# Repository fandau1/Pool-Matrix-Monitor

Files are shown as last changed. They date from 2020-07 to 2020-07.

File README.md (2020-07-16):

# Pool-Matrix-Monitor




**Simple arduino pool clock with sensors**

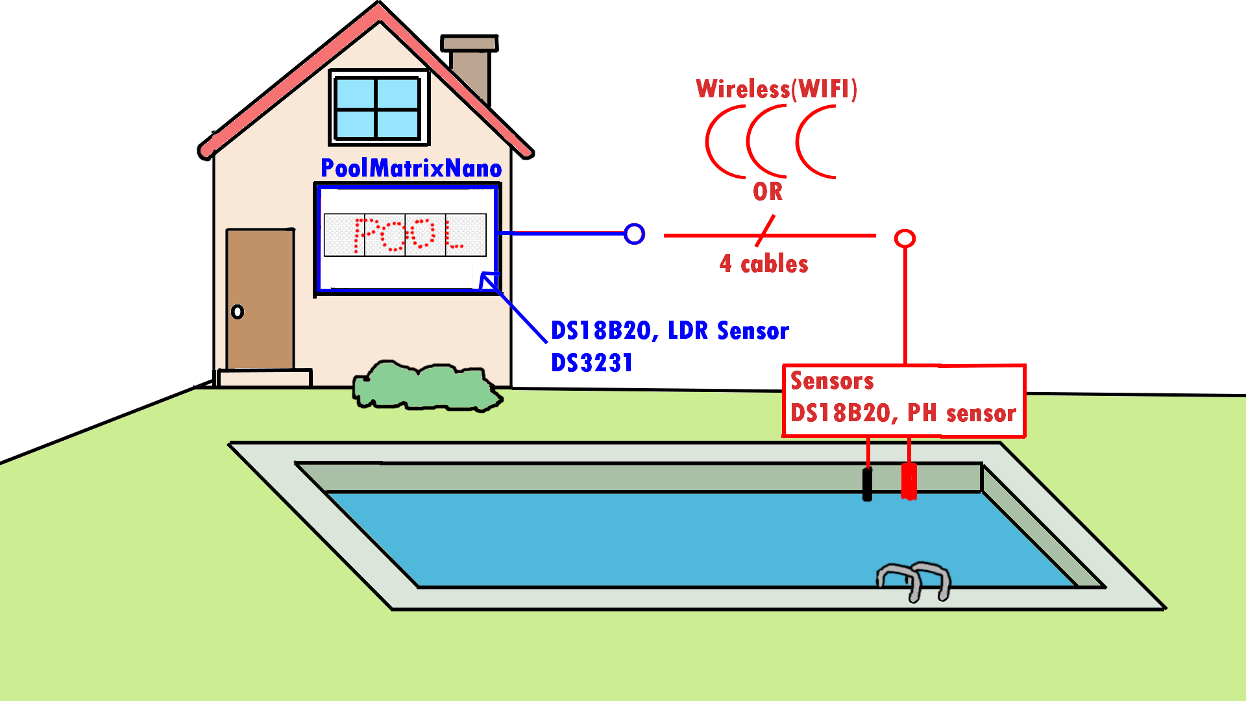
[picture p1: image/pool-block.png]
  

Pool-Matrix-Monitor is pool clock with temperature, ph sensor and all this data send to ThingSpeak, or GET to server.

# Main Features
  * [x] Matrix display in cycle(TIME,"Outsite",OUTSITE_TEMPERATURE,"Pool",POOL_TEMPERATURE,"PH sensor", POOL_PH)
  * [x] Measurement of Sensors light, temperature, ph
  * [x] Auto detection connected sensors
  * [x] Auto correct summer and standart time (DST correct)

# How to use?
  **1.** Choose Optimal Board version. Project is saved in **__NAME_OF_BOARD__/...** (example **PoolMatrixNano/...**)  
  **2.** Create circuit or pcb  
  **3.** Upload Arduino Software with Arduino IDE  
  **4.** Put sensors in conectors and you can put in box  

  **[Full Tutorial in CZ language here](https://github.com/fandau1/Pool-Matrix-Monitor/blob/master/TutorialCZ.md)**

# Boards Versions
I have prepering more version of this project so you can choose which is best for you.

|  Boards Versions  | MCU | transfer type pool sensor | SW release | HW release |  Price  |
| :---: |:---:| :---: | :---: | :---: | :---: |
| [PoolMatrixNano](#poolmatrixnano) | Arduino nano | cable | PMN-v1.0 | PMN-v1.1H | ~13$ |
| PoolMatrixNanoEth | Arduino nano | cable | Not realesed | Not realesed |  |
| PoolMatrixESP32 | ESP32 | cable OR WIFI | Not realesed | Not realesed |  |
| PoolMatrixESP8266 | ESP8266 | cable OR WIFI | Not realesed | Not realesed | |

**for more info with tutorial go to section [All Boards list](boards.md)**

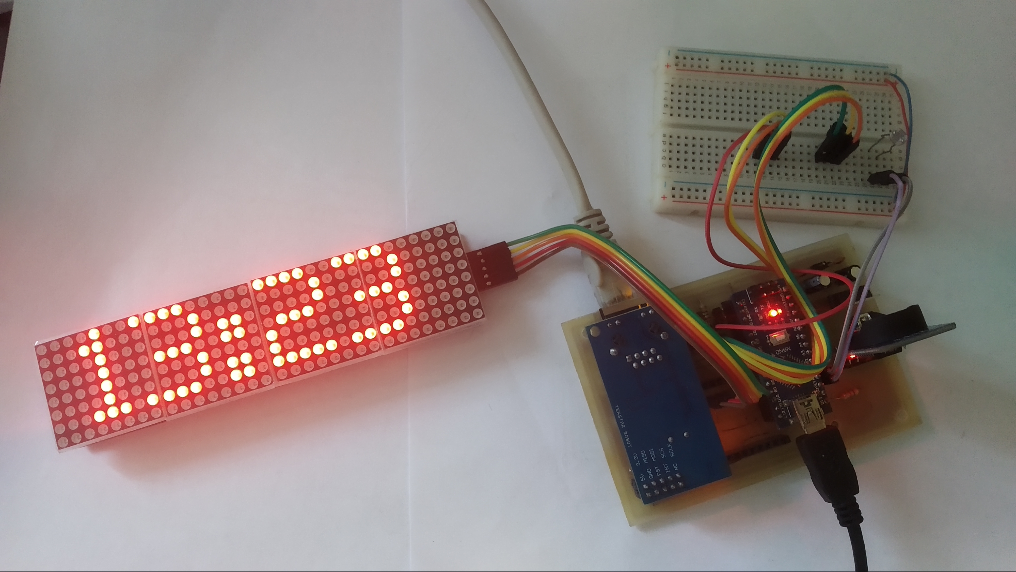
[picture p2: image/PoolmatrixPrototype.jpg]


## PoolMatrixNano [[Full version](boards.md#poolmatrixnano)]
**Offline board arduino nano mcu with rtc, matrix display and sensors. Simple cheap and easy for home pool.**

**Basic**
  * Arduino nano
  * DS3231
  * MAX7219 Matrix LED Display Module 4-v-1
  * some resistors

**Optional**
  * DS18B20 *- temperature sensor*
  * Photo Resistor
  * PH sensor PH-4502C

# PCB
  I designed PCB oneside only with some proclaim wires :). So, you can easily create in home or you can solder on prototype pcb. PCB is saved in **__NAME_OF_BOARD__/pcb/** you can choose more version(no ethernet, etc.).

  **PS: In this time you can choose only PoolMatrixNano**

# Installation
 * Download below library and upload code with Arduino IDE to arduino nano. Code is saved in **__NAME_OF_BOARD__/src/** you can choose more version(no ethernet, etc.).

 **In MD_Parola library you must to disable all advance function for a smaller size.**

 **PS: In this time you can choose only PoolMatrixNano**

**Library**
  * [MD_MAX72xx](https://github.com/MajicDesigns/MD_MAX72XX) - *from MajicDesigns*
  * [RTClib](https://github.com/adafruit/RTClib) - *from adafruit*
  * [DallasTemperature](https://github.com/milesburton/Arduino-Temperature-Control-Library) - *from milesburton*
  * [Ethernet2](https://github.com/adafruit/Ethernet2) - *from adafruit*
  * [DST_RTC](https://github.com/andydoro/DST_RTC) - *from andydoro*  

## Planned Features
  * [ ] send data to database (MYSQL), ThingSpeak
  * [ ] ESP8266/ESP32 version
  * [x] NTP synchronize time

## Support
Project is supported if you have any problem contact me. Please give me a :star: if you like my project. If you have any problem feel free and contact me.

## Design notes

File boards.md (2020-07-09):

# Boards Versions
|  Board Versions  | MCU | transfer type pool sensor | SW release | HW release |  Approximate price  |
| :---: |:---:| :---: | :---: | :---: | :---: |
|[PoolMatrixNano](#poolmatrixnano)  | Arduino nano | cable | PMN-v1.1H | PMN-v1.0 | ~13$ |
| PoolMatrixNanoEth | Arduino nano | cable | Not realesed | Not realesed |  |
| PoolMatrixESP32 | ESP32 | cable OR WIFI | Not realesed | Not realesed |  |
| PoolMatrixESP8266 | ESP8266 | cable OR WIFI | Not realesed | Not realesed | |

# PoolMatrixNano
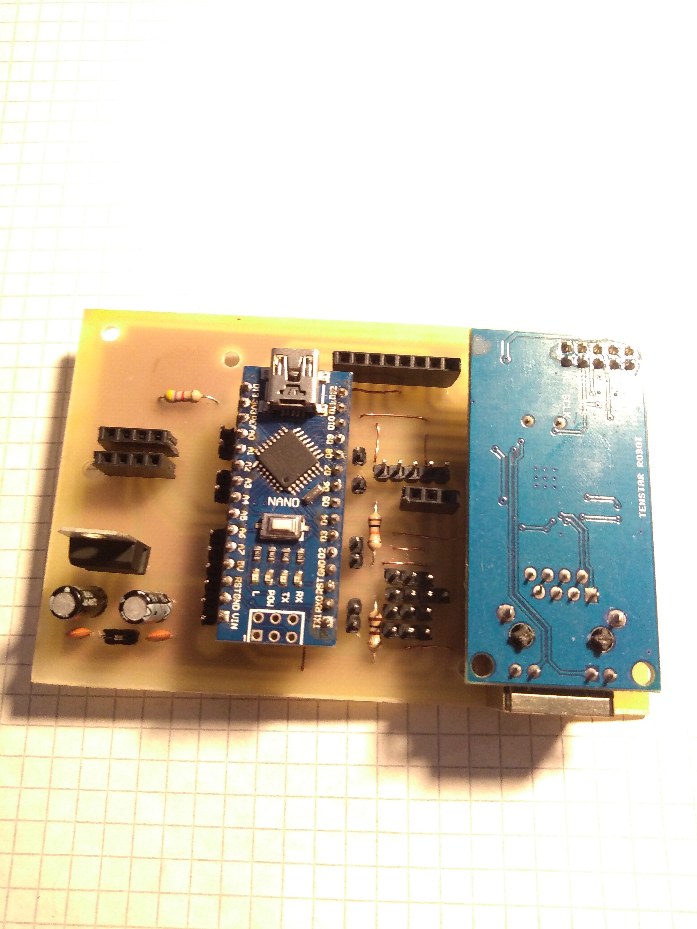
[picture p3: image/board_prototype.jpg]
 

Offline arduino nano mcu with rtc, matrix display and sensors. Simple cheap and easy for home pool.

## Components
**Basic**
  * Arduino nano
  * DS3231
  * MAX7219 Matrix LED Display Module 4-v-1
  * some resistors
  
**Optional**
  * DS18B20 *- temperature sensor*
  * Photo Resistor
  * PH sensor PH-4502C 
    
## Schematic
|  Arduino  | |  Modules  |
| :---: |---|  :---: |
| D13(SCK) | -> |  MATRIX(CLK) |
| D11(MOSI) | -> |  MATRIX(DIN) |
| D10(SS) | -> | MATRIX(CS) |
| D5(PWM) | -> | DS18B20 |
| A5(SCL) | -> | DS3231(SCL) |
| A4(SDA) | -> | DS3231(SDA) |
| A1 | -> | PH sensor |
| A0 | -> | Photo resistor(LUX meter) |

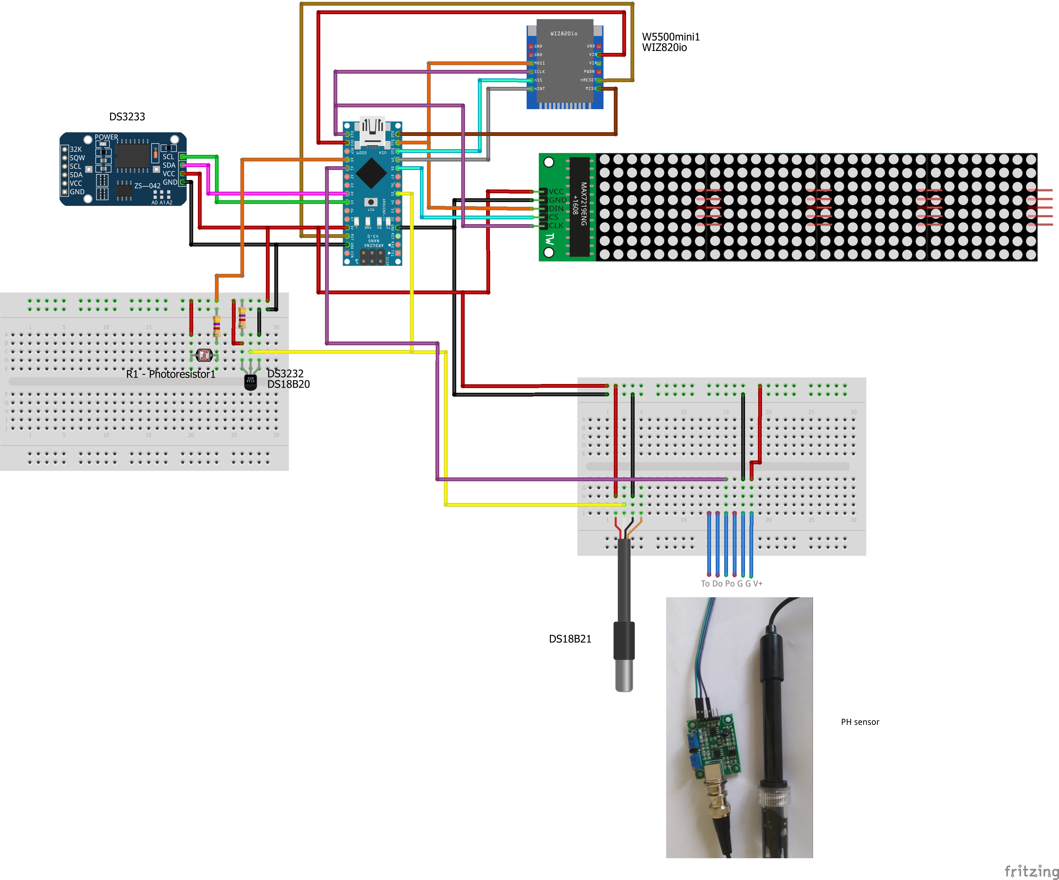
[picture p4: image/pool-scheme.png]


## PCB
I designed PCB oneside only with some proclaim wires :). So, you can easily create in home or you can solder on prototype pcb. PCB is saved in **pcb/...** you can choose more version(no ethernet, etc.).

## Tutorial
First, it is important to engage the schematic. You can plug it into a breadboard or use my pcb design. It is also possible to connect a circuit to a prototype pcb if you do not have the ability to produce a pcb. PCB is saved in **pcb/...** you can choose more version(no ethernet, etc.).

If you do not want any sum in the optional section, you do not need to use it. The code will work. So if you don't want a ph sensor, you don't have to connect it. 

**So far, I do not recommend using a ph sensor too much, because it seems inaccurate and expensive.**

After you complete HW section. You can upload code with Arduino IDE(must download all library). Code is saved in **src/...** you can choose more version(no ethernet, etc.).

**In *MD_Parola* library you must to disable all advance function for a smaller size.**

And your pool-matrix-monitor is done. You can test it and choose in some nice box.

if you have any problems feel free to contact me.

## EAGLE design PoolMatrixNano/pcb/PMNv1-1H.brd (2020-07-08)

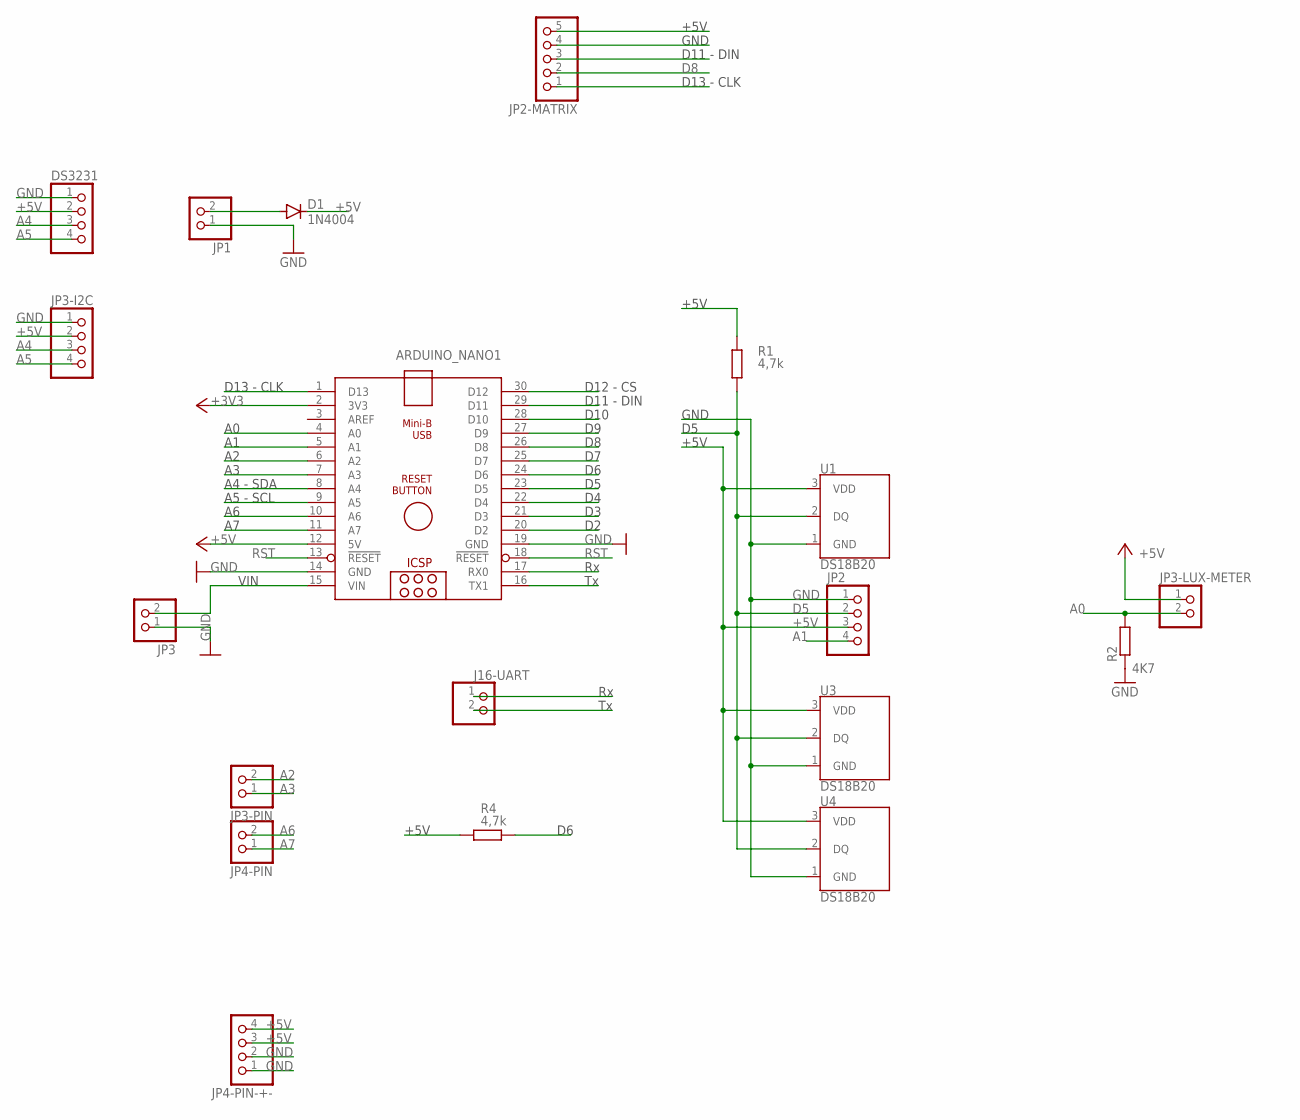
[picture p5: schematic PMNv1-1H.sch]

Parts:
ARDUINO_NANO1: ARDUINO_NANO
D1: 1N4004; DO41-10
DS3231: PINHD-1X4; 1X04
J16-UART: PINHD-1X2; 1X02
JP1, JP3, JP3-LUX-METER, JP3-PIN, JP4-PIN: PINHD-1X2; 1X02
JP2, JP3-I2C, JP4-PIN-+-: PINHD-1X4; 1X04
JP2-MATRIX: PINHD-1X5; 1X05
R1, R4: 4,7k; 0204/7
R2: 4K7; 0207/10
U1, U3, U4: DS18B20; TO-92-AMMO

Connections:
+3V3: ARDUINO_NANO1.2 (3V3)
+5V: ARDUINO_NANO1.12 (5V), D1.C, DS3231.2, JP2.3, JP2-MATRIX.5, JP3-I2C.2, JP3-LUX-METER.1, JP4-PIN-+-.3, JP4-PIN-+-.4, R1.1, R4.1, U1.3 (VDD), U3.3 (VDD), U4.3 (VDD)
A0: ARDUINO_NANO1.4 (A0), JP3-LUX-METER.2, R2.2
A1: ARDUINO_NANO1.5 (A1), JP2.4
A2: ARDUINO_NANO1.6 (A2), JP3-PIN.2
A3: ARDUINO_NANO1.7 (A3), JP3-PIN.1
A4: ARDUINO_NANO1.8 (A4), DS3231.3, JP3-I2C.3
A5: ARDUINO_NANO1.9 (A5), DS3231.4, JP3-I2C.4
A6: ARDUINO_NANO1.10 (A6), JP4-PIN.2
A7: ARDUINO_NANO1.11 (A7), JP4-PIN.1
D2: ARDUINO_NANO1.20 (D2)
D3: ARDUINO_NANO1.21 (D3)
D4: ARDUINO_NANO1.22 (D4)
D5: ARDUINO_NANO1.23 (D5), JP2.2, R1.2, U1.2 (DQ), U3.2 (DQ), U4.2 (DQ)
D6: ARDUINO_NANO1.24 (D6), R4.2
D7: ARDUINO_NANO1.25 (D7)
D8: ARDUINO_NANO1.26 (D8), JP2-MATRIX.2
D9: ARDUINO_NANO1.27 (D9)
D10: ARDUINO_NANO1.28 (D10)
D11: ARDUINO_NANO1.29 (D11), JP2-MATRIX.3
D12: ARDUINO_NANO1.30 (D12)
D13: ARDUINO_NANO1.1 (D13), JP2-MATRIX.1
GND: ARDUINO_NANO1.14 (GND), ARDUINO_NANO1.19 (GND), DS3231.1, JP1.1, JP2.1, JP2-MATRIX.4, JP3.1, JP3-I2C.1, JP4-PIN-+-.1, JP4-PIN-+-.2, R2.1, U1.1 (GND), U3.1 (GND), U4.1 (GND)
unnamed: D1.A, JP1.2
RST: ARDUINO_NANO1.13 (!RESET), ARDUINO_NANO1.18 (!RESET)
RX: ARDUINO_NANO1.17 (RX0), J16-UART.1
TX: ARDUINO_NANO1.16 (TX1), J16-UART.2
VIN: ARDUINO_NANO1.15 (VIN), JP3.2

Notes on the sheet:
A4 - SDA
A5 - SCL
D13 - CLK
GND
+5V
D12 - CS
D11 - DIN
D10
VIN

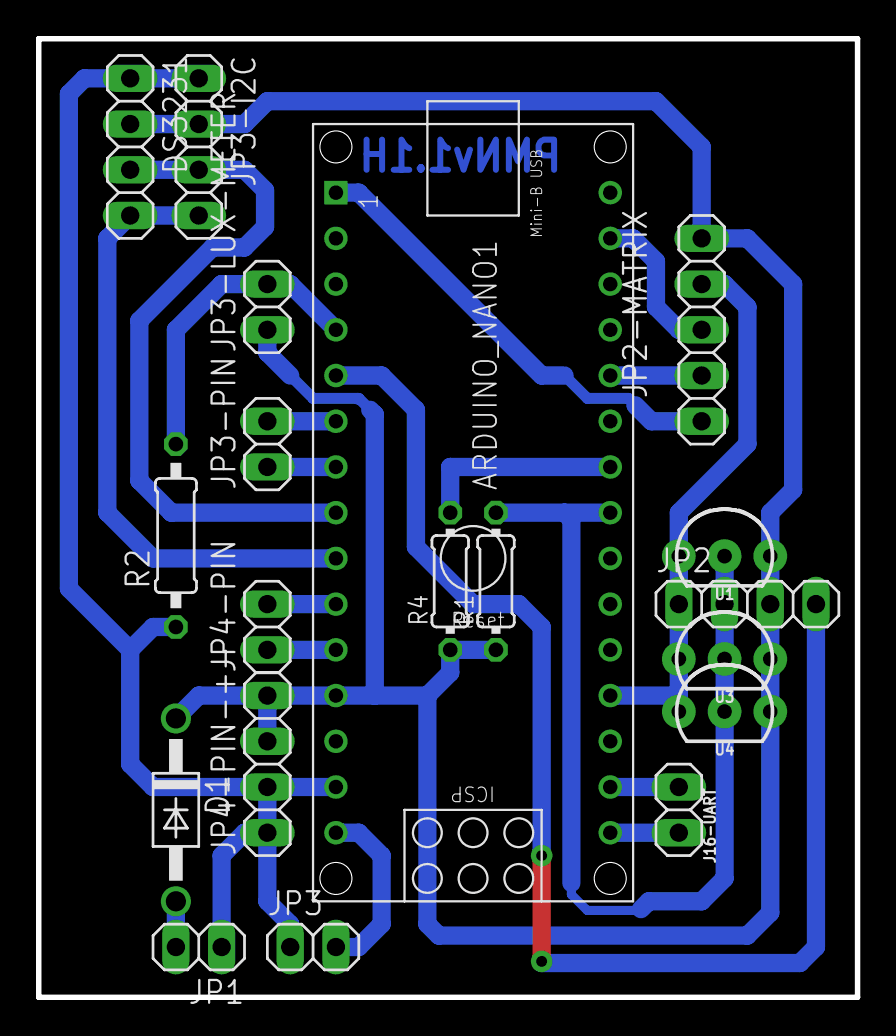
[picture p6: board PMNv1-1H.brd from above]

Board: 2 copper layers, 45.5 x 53.3 mm, 19 parts (0 on the bottom side), 20 nets.

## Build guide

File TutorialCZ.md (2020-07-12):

# Tutorial Pool-Matrix-Monitor
  

## Úvod
Zdavím, nápad udělat si vlastní teploměr k bazénu mě napadl po používání teploměru "zvířátka". Tento teploměr je velký, ale hlavně musíte šahat do vody, pokud chcete znát teplotu. Proto mě napadl nápad udělat si vlastní hodiny s teploměrem, který bude měřit venkovní a bazénovou teplotu. Inspiraci na displej jsem vzal z průmyslových hodin teploměrů, které se používají na plaveckém bazénu

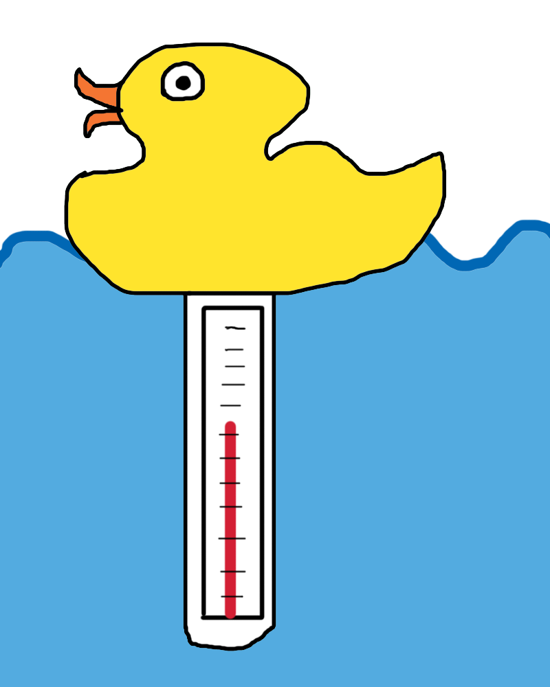
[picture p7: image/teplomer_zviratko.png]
  

*teploměr zvířátka, prumyslove bazenove hodiny*
*(kresleno kvuli copyrightu)*

Myšlenkou tedy bylo vyrobit hodiny s teploměrem a vše zobrazovat na displeji. Jako displej jsem zvolil maticový displej, konkrétně se 4 maticovými moduly. Dalo by se sice asi využít segmisegmentovku s pár diodami, ale tohle se mi zdá jednoduší na výrobu. Obvod řídí Arduino nano a čas zaznamenává RTC modul DS3231. Tento projekt měří venkovní a bazénovou teplotu, pro měření jsou použity sensory DS18B20. pro venkovní je použita verze s pouzdrem TO92 a v bazénu je použita vodotěsná verze. Takže to jsou všechny hlavní součásky, nepočítám do toho resistory a konektory. Protože jsem použil čínské moduly dostal jsem se na cenu cca ~300kč (bez krabičky).

## 0. Možnosti Bazénu
Pokud si tedy chcete vyrobit taky takové hodiny s teploměrem. Doporučuji vám si před tím určit, kam chcete displej umístit, a kam umístíte do bazénu teploměr. K Bazénovému temploměru je nutné přivést 3 dráty od arduina (+5V, GND, DigitalPin). K samotnému displeji je potřeba přivéct dráty pro napájení (+5V,GND).

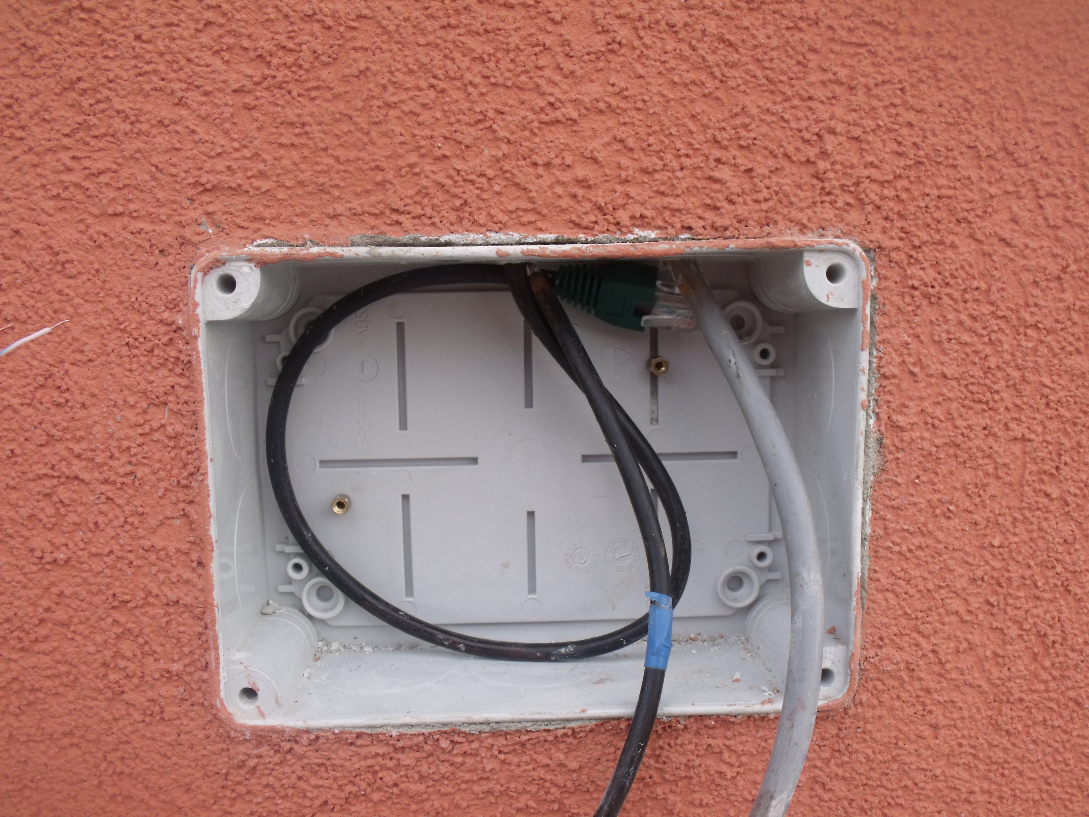
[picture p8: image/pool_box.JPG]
   

*Foto mého řešení krabičky a sensoru u bazénu*

K napájení je nutné použít 5V. Napájení přes VIN konektor podle mě není možný kvůli vyššímu proudu, který by způsobil spálení stabilizátoru na desce arduino nano. I když je možné, že pokud to budete napájet přes VIN třeba 7V, že to bude fungovat nemám to však odzkoušené.

## 1. Deska plošného spoje (Obvod)
Protože mám doma možnost vyrábět jednostranné DPS, tak jsem navrhl jednostranou desku s pár "proklemováky" (nevim jak se tomu na DPS říká asi nijak prostě místo druhé vrstvy to propojím drátkem). Protože je tohle, ale tutoriál a ne všichni mají možnost vyrobit si DPS. Je zde možnost zapojit to na prototype board, nebo rovnou připájet moduly a součástky k sobě. (případně pokud si chcete projekt pouze vyzkoušet na breadboard). Pokud tedy nechcete vyrábět DPS přejděte na část 1.2

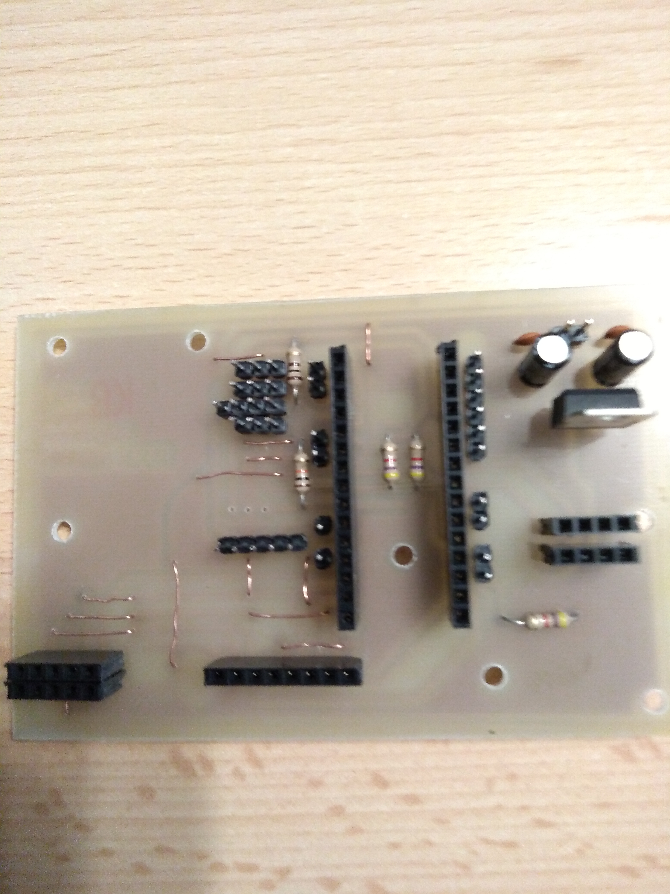
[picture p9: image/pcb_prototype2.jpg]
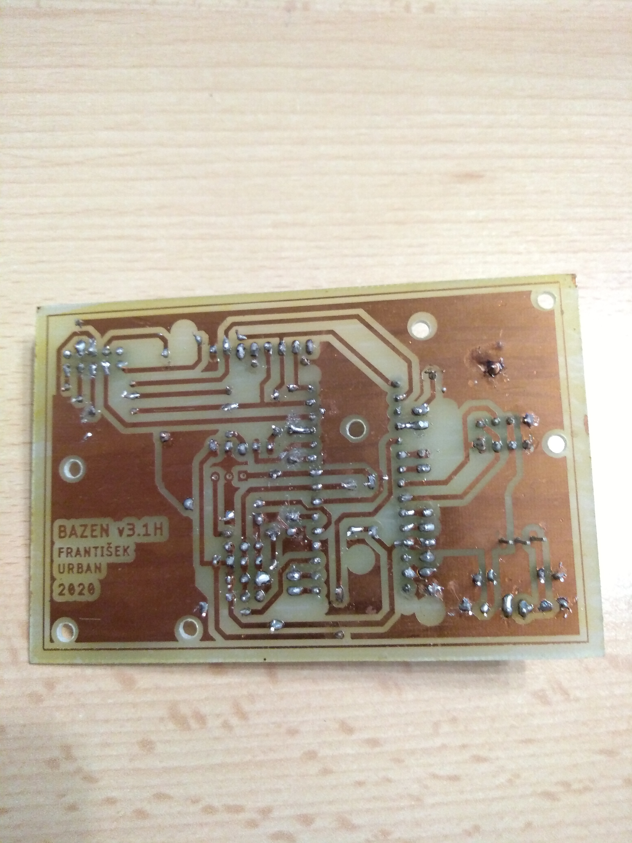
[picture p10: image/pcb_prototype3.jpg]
  

*ukázka trochu jiné verze DPS*

Pokud jste se rozhodli vyrobit si DPS použijte svoji oblíbenou metodu, já znám 3 a všechny jsem vyzkoušel(+1 kterou jsem nezkoušel). První metoda se jmenuje "Toner transfer" tato metoda spočívá v přenosu toneru z papíru na DPS a následné vyleptání. Mě se však tato metoda vůbec neosvětčila. Proto bych doporučil metodu 2. Druhá metoda spočívá v přenosu obvodu pomocí photocitlivé vrstvy na DPS, k tomu jsou nutné DPS s nanesenou vrstvou. Obvod se vytiskne na fólie a přenese přes UV záření, které vysvítí vrstvu na desce. Další metody jsou přes "Uv Dry Film"(stejná jako 2 metoda s tím že není vrstva nanesena ale musíme ji nanést), CNC frézou.

*Projekt je uložen v adresáři **/PoolMatrixNano/** Deska je pak uložena ve složce pcb*

 

*Positiv a negativ DPS*

## 1.1 Seznam Součástek
|  Součástka  | Počet |  Cena  |
| :---: | :---: |  ---: |
|  **Základní**  | |
|  Arduino nano  | 1 | 43Kč |
|  RTC DS3231  | 1 | 25Kč |
|  MAX7219 Matrix LED Display Module 4-v-1  | 1 | 72Kč |
|  dioda 1N4007  | 1 | 1Kč |
|  resistor 4K7  | 2 | 1Kč |
|  **Volitelné**  | |
|  DS18B20 TO92  | 1 | 20Kč |
|  DS18B20 WaterProof | 1 | 22Kč |
|  Photo resistor  | 1 | 1Kč |
|  Pinheaders  | 1 | 48Kč |
|  **Cena základní**  || 142Kč |
|  **Cena maximální**  || 233Kč |

*Ceny jsou orientační a nejsou včetně poštovného*



*Ukázka mojí prototypové desky s ethernetem*

## 1.2 Zapojení schéma
|  Arduino  | |  Modules  |
| :---: |:-:|  :---: |
| D13(SCK) | -> |  MATRIX(CLK) |
| D11(MOSI) | -> |  MATRIX(DIN) |
| D10(SS) | -> | MATRIX(CS) |
| D5(PWM) | -> | DS18B20 |
| A5(SCL) | -> | DS3231(SCL) |
| A4(SDA) | -> | DS3231(SDA) |
| A1 | -> | PH sensor |
| A0 | -> | Photo resistor(LUX meter) |

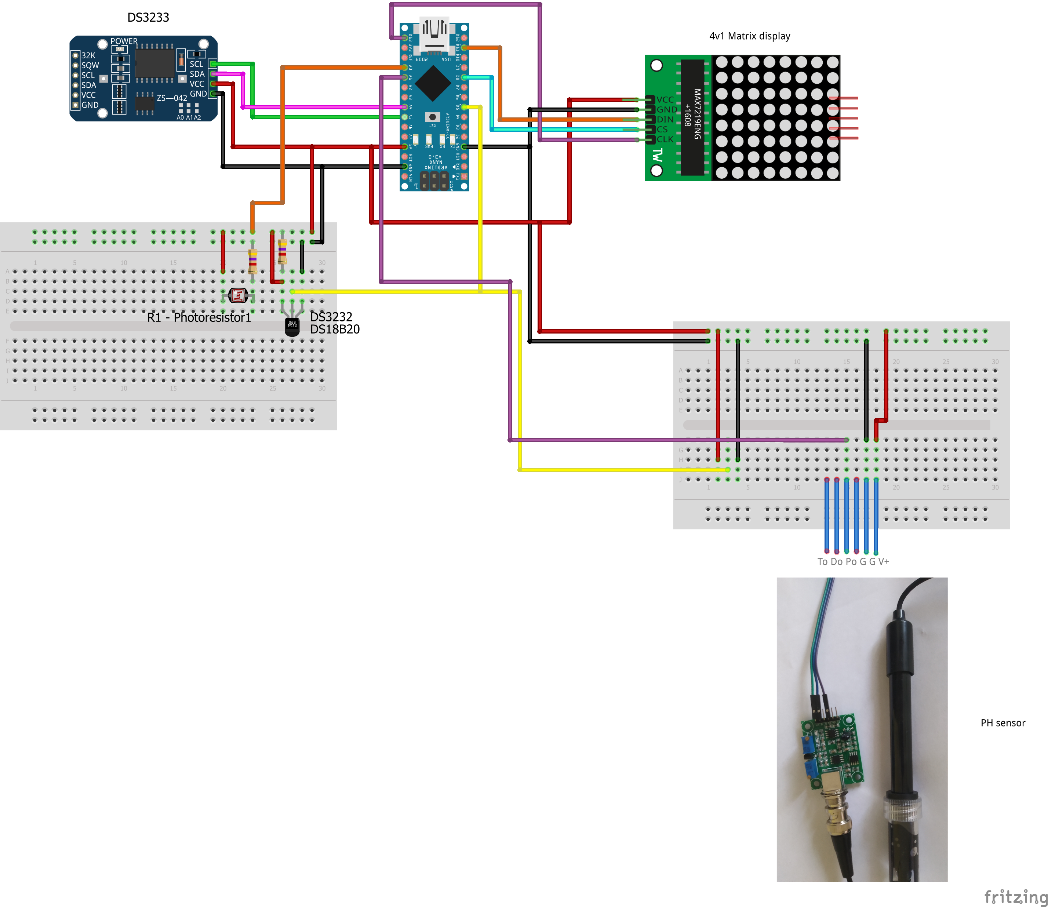
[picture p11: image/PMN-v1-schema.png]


## 2. Nahrání Softwaru
Software se nahraje v Arduino IDE, přes usb do arduino nano. Potřebný kód je ve složce **/PoolMatrixNano/arduino-code**. V programu je i příprava na PH sensor (která není zahrnuta do kodu), ale zřejmě jej nedodělám protože je docela nepřesný a drahý. Aby jste byly schopný nahrát kód je nutné stáhnout knihovny níže. V knihovně MD_Parola musíte vypnou nadstadardní funkce viz foto (jinak by se program nevešel na arduino nano).

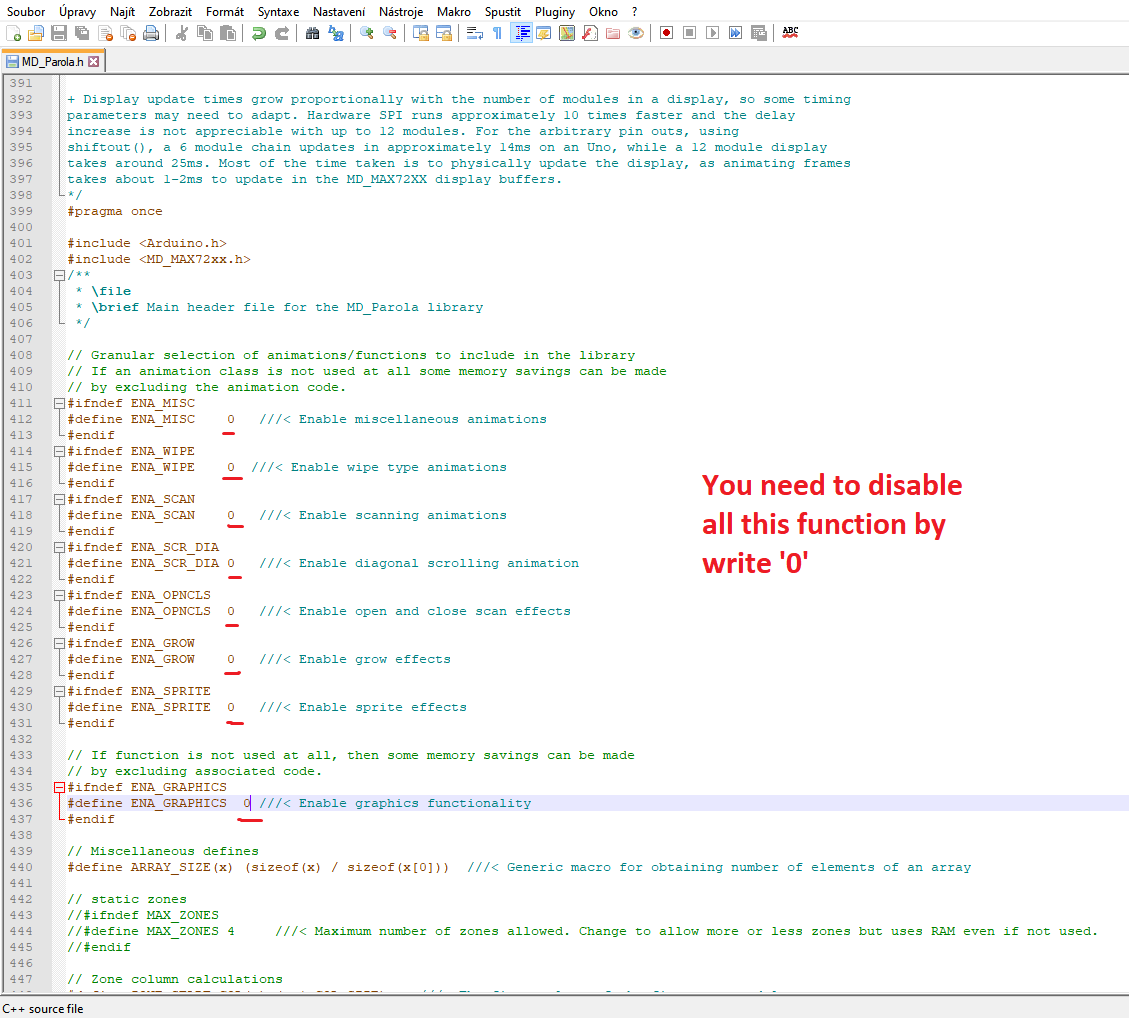
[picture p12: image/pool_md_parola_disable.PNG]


**V MD_Parola library musíte  vypnout nadstadardní funkce**

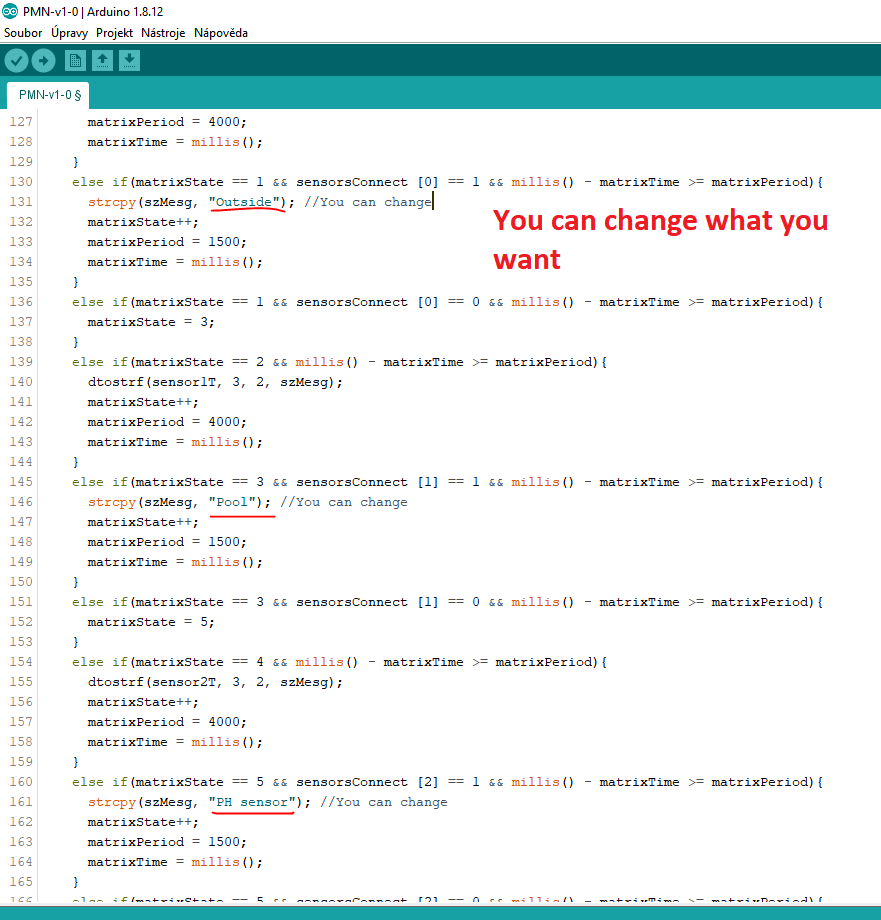
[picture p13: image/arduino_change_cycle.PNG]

Zde jsi můžete přenastavit text, který se zobrazuje na maticovce

**Library**
 * [MD_MAX72xx](https://github.com/MajicDesigns/MD_MAX72XX) - *from MajicDesigns*
 * [RTClib](https://github.com/adafruit/RTClib) - *from adafruit*
 * [DallasTemperature](https://github.com/milesburton/Arduino-Temperature-Control-Library) - *from milesburton*
 * [Ethernet2](https://github.com/adafruit/Ethernet2) - *from adafruit*
 * [DST_RTC](https://github.com/andydoro/DST_RTC) - *from andydoro*  

*Projekt je uložen v adresáři **/PoolMatrixNano/** Deska je pak uložena ve složce arduino-code*

## Závěr
Tak to jsou moje hodiny k bazénu. Pokud se vám tutoriál a projekt líbil dejte :star: na můj projekt na GitHubu. Pokud by jste měli nějaké problémy, nebo pokud je v programu nebo v HW chyba neváhejte mě kontaktovat. Projekt hodlám ještě vytvořit na ESP32 a připojit ho tak k internetu.

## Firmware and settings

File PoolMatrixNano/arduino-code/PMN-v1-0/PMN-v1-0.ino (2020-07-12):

/*
 * Version: v1.0

 */
/* Import library */
#include <RTClib.h>
#include <Wire.h>
#include <MD_Parola.h>
#include <MD_MAX72xx.h>
#include <SPI.h>
#include <OneWire.h> 
#include <DallasTemperature.h>
#include <DST_RTC.h>
#include <avr/wdt.h>

/* Define pins you can change if you want */
#define DIN_PIN 11
#define CLK_PIN 13
#define CS_PIN 8
#define PIN_SENSOR_DS18B20 5
#define PIN_SENSOR_PH A1 
#define PIN_SENSOR_LDR A0 

/* Import library */
// Define the number of devices we have in the chain and the hardware interface
// NOTE: These pin numbers will probably not work with your hardware and may
// need to be adapted
#define HARDWARE_TYPE MD_MAX72XX::FC16_HW
#define MAX_DEVICES 4

#define SPEED_TIME  50
#define PAUSE_TIME  100
#define MAX_MESG  8

// HARDWARE SPI
MD_Parola P = MD_Parola(HARDWARE_TYPE, CS_PIN, MAX_DEVICES);
// SOFTWARE SPI
//MD_Parola P = MD_Parola(HARDWARE_TYPE, DIN_PIN, CLK_PIN, CS_PIN, MAX_DEVICES);

/* Configure RTC DS3231 */
//hodiny DS3231
RTC_DS3231 rtc; // SDA A4, SCL A5
DST_RTC dst_rtc; // DST object

//char daysOfTheWeek[7][12] = {"Sunday", "Monday", "Tuesday", "Wednesday", "Thursday", "Friday", "Saturday"};

/* Configure DS18B20 */
OneWire oneWireDS1(PIN_SENSOR_DS18B20);
DallasTemperature sensorsDS1(&oneWireDS1);

/* Constatns for LDR sensor */
// These constants, define values needed for the LDR readings and ADC
#define MAX_ADC_READING           1023
#define ADC_REF_VOLTAGE           5.0
#define REF_RESISTANCE            4700 // measure this for best results
#define LUX_CALC_SCALAR           12518931
#define LUX_CALC_EXPONENT         -1.405

//LDR sensor variables
int sensorLdrCount;
float sensorLdrAvg; //Average
float sensorLdrSum;
int sensorLdrRawSum;
int sensorLdrRawAvg; //Average
unsigned long sensorLdrTime;
unsigned long sensorLdrPeriod = 1000; //Period for LDR measurement in 10 count does mean with 6000 = 6s*10 = 1 minute for LDR measurement

//DS18B20 variables
float sensor1T; //T as temperature
float sensor2T;

//variable for PH sensor
float sensorPh;

//variable for conntected sensors
bool sensorsConnect [3];

//variables for matrix display
char  szMesg[MAX_MESG+1] = "Boot";
int matrixState;
unsigned long matrixTime;
unsigned long matrixPeriod; 



void setup() {
  // initialization of communication via serial line at 9600 baud
  Serial.begin(9600);
  
  // Nastavení maticovky
  P.begin();
  P.setIntensity (3); //0-15 
  P.setZone(0, 0, MAX_DEVICES-1);
  P.setIntensity (3); //0-15 
  P.displayZoneText(0, szMesg, PA_CENTER, SPEED_TIME, PAUSE_TIME, PA_PRINT, PA_NO_EFFECT);
  //P.displayZoneText(0, szMesg, SPEED_TIME, PAUSE_TIME, PA_SCROLL_LEFT, PA_SCROLL_LEFT);

  //run rtc
  Wire.begin();
  rtc.begin();

  //Setup DS18B20
  sensorsDS1.begin();

  wdt_enable(WDTO_8S);
}


void loop() {
  Intensity();
  MatrixCycle();
  wdt_reset();
}

void MatrixCycle(){ 
  P.displayAnimate();
  if (P.getZoneStatus(0)){  
    if(matrixState == 0 && millis() - matrixTime >= matrixPeriod){
      DateTime standardTime = rtc.now();
      DateTime DstTime = dst_rtc.calculateTime(standardTime); // takes into account DST
      //move to 'szMesg' time in the form 'hh: mm' (that will appear on buffer and display on matrix)
      char buf1[] = "hh:mm";
      strcpy(szMesg, DstTime.toString(buf1));     
      SenzorsDS();
      sensorPH();
      matrixState++; 
      matrixPeriod = 4000; 
      matrixTime = millis();  
    }
    else if(matrixState == 1 && sensorsConnect [0] == 1 && millis() - matrixTime >= matrixPeriod){
      strcpy(szMesg, "Outside"); //You can change
      matrixState++; 
      matrixPeriod = 1500;   
      matrixTime = millis();   
    }
    else if(matrixState == 1 && sensorsConnect [0] == 0 && millis() - matrixTime >= matrixPeriod){
      matrixState = 3;   
    }
    else if(matrixState == 2 && millis() - matrixTime >= matrixPeriod){
      dtostrf(sensor1T, 3, 2, szMesg);
      matrixState++;             
      matrixPeriod = 4000;  
      matrixTime = millis();      
    }
    else if(matrixState == 3 && sensorsConnect [1] == 1 && millis() - matrixTime >= matrixPeriod){
      strcpy(szMesg, "Pool"); //You can change
      matrixState++; 
      matrixPeriod = 1500;
      matrixTime = millis();      
    }
    else if(matrixState == 3 && sensorsConnect [1] == 0 && millis() - matrixTime >= matrixPeriod){
      matrixState = 5;   
    }
    else if(matrixState == 4 && millis() - matrixTime >= matrixPeriod){
      dtostrf(sensor2T, 3, 2, szMesg);
      matrixState++; 
      matrixPeriod = 4000;
      matrixTime = millis();       
    }
    else if(matrixState == 5 && sensorsConnect [2] == 1 && millis() - matrixTime >= matrixPeriod){
      strcpy(szMesg, "PH sensor"); //You can change
      matrixState++; 
      matrixPeriod = 1500;
      matrixTime = millis();      
    }
    else if(matrixState == 5 && sensorsConnect [2] == 0 && millis() - matrixTime >= matrixPeriod){
      matrixState = 0;   
    }
    else if(matrixState == 6 && millis() - matrixTime >= matrixPeriod){
      dtostrf(sensorPh, 3, 2, szMesg);
      matrixState = 0; 
      matrixPeriod = 4000;
      matrixTime = millis();      
    }     
    P.displayReset(0);  
  } 
}

void SenzorsDS(){
  // Temperature reading
  sensorsDS1.requestTemperatures();
  sensor1T = sensorsDS1.getTempCByIndex(0); 
  sensor2T = sensorsDS1.getTempCByIndex(1);
  if(sensor1T == -127){
    sensorsConnect [0] = 0; 
  }
  else{
    sensorsConnect [0] = 1;   
  }
  if(sensor2T == -127){
    sensorsConnect [1] = 0;   
  }
  else{
    sensorsConnect [1] = 1;   
  }

}

void Intensity(){
  if(millis() - sensorLdrTime >= sensorLdrPeriod){
    // Perform the analog to digital conversion  
    int sensorLdrRaw = analogRead(0);
    /*// RESISTOR VOLTAGE_CONVERSION
    // Convert the raw digital data back to the voltage that was measured on the analog pin
    float sensorLdrResiV = (float)sensorLdrRaw / MAX_ADC_READING * ADC_REF_VOLTAGE;
    // voltage across the LDR is the 5V supply minus the 5k resistor voltage
    float sensorLdrV = ADC_REF_VOLTAGE - sensorLdrResiV;
    // LDR_RESISTANCE_CONVERSION
    // resistance that the LDR would have for that voltage  
    float sensorLdrR = sensorLdrV/sensorLdrResiV * REF_RESISTANCE;
    // LDR_LUX
    // Change the code below to the proper conversion from ldrResistance to
    // ldrLux
    float sensorLdrLux = LUX_CALC_SCALAR * pow(sensorLdrR, LUX_CALC_EXPONENT);*/
    float sensorLdrLux = LUX_CALC_SCALAR * pow(((ADC_REF_VOLTAGE - ((float)sensorLdrRaw / MAX_ADC_READING * ADC_REF_VOLTAGE))/((float)sensorLdrRaw / MAX_ADC_READING * ADC_REF_VOLTAGE) * REF_RESISTANCE), LUX_CALC_EXPONENT);
    sensorLdrSum = sensorLdrSum + sensorLdrLux;
    sensorLdrRawSum = sensorLdrRawSum + sensorLdrRaw;
    sensorLdrCount++;
    Serial.println(sensorLdrCount);
    Serial.print("RAW LDR: ");        
    Serial.println(sensorLdrRaw);    
    if(sensorLdrCount >= 10){
      sensorLdrAvg = sensorLdrSum / sensorLdrCount;
      sensorLdrRawAvg = sensorLdrRawSum / sensorLdrCount;      
      sensorLdrCount = 0;
      sensorLdrSum = 0;
      sensorLdrRawSum = 0;  
      sensorsConnect [3] = 1; 
      //setup automatic light of matrix
      if(sensorLdrRawAvg<=10){
        //<10 LDR is unconected
        P.setIntensity (3); // setup matrix intensity 0-15 
        sensorsConnect [3] = 0;    
      } 
      else if(sensorLdrRawAvg<=100){
        P.setIntensity (1); // setup matrix intensity 0-15 
      }
      else if(sensorLdrRawAvg<=200){
        P.setIntensity (2); // setup matrix intensity 0-15 
      }
      else if(sensorLdrRawAvg<=300){
        P.setIntensity (2); // setup matrix intensity 0-15 
      }
      else if(sensorLdrRawAvg<=600){
        P.setIntensity (3); // setup matrix intensity 0-15 
      }
      else if(sensorLdrRawAvg<=700){
        P.setIntensity (4); // setup matrix intensity 0-15 
      }
      else if(sensorLdrRawAvg<=800){
        P.setIntensity (5); // setup matrix intensity 0-15 
      }
      else if(sensorLdrRawAvg>=900){
        P.setIntensity (8); // setup matrix intensity 0-15 
      }   
    }   
    sensorLdrTime = millis();
  }  
}

void sensorPH(){
  // create help variables
  int sensorPhArray[10];
  int backup;
  unsigned long int sensorPhCalcAvg = 0;
  // reading ten samples after 10 ms into the field
  for (int i = 0; i < 10; i++) {
    sensorPhArray[i] = analogRead(PIN_SENSOR_PH);
    delay(10);
  }
  for (int i = 0; i < 10; i++) {
    Serial.print(sensorPhArray[i]);
    Serial.print(" | ");
  }
    Serial.println(" ");
  // sorting the members of the measured results field by size
  for (int i = 0; i < 9; i++) {
    for (int j = i + 1; j < 10; j++) {
      if (sensorPhArray[i] > sensorPhArray[j]) {
        backup = sensorPhArray[i];
        sensorPhArray[i] = sensorPhArray[j];
        sensorPhArray[j] = backup;
      }
    }
  }
  // save the 2nd to 8th result in variables from which the average is calculated
  // (omit two array members at the beginning and end for better accuracy)
  for (int i = 2; i < 8; i++) {
    sensorPhCalcAvg += sensorPhArray[i];
  }
  // calculation of pH value from average
  // measurement and conversion to the range 0-14 pH
  float sensorPhAvg = (float)sensorPhCalcAvg * 5.0 / 1024 / 6;
  sensorPh = -5.70 * sensorPhAvg + 21.34 + 2;
}

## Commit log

2020-07-07 prototype images
2020-07-09 v1.0 change
    change structure directory
    [PMNv1-1H.brd, PMNv1-1H.sch]

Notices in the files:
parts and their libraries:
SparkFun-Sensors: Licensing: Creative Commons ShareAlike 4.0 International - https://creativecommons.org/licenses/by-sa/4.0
